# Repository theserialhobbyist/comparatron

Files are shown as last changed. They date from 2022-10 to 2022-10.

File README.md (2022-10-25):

# comparatron
Comparatron - a DIY digital optical comparator

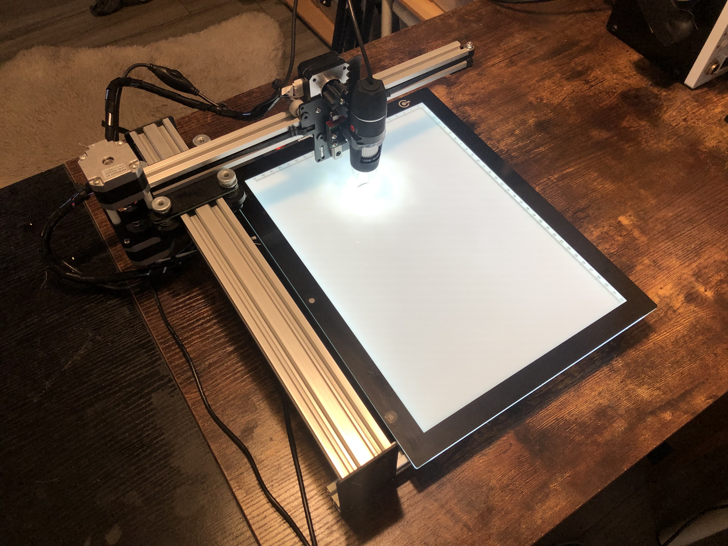
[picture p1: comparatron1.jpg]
Comparatron


This is a DIY digital optical comparator, which is an instrument used to take precise measurements of physical objects through visual means. Optical comparators cost tens of thousands of dollars, but Comparatron costs less than $500 to build (most of that cost is the CNC pen plotter).

It is essentially a USB digital microscope mounted to a CNC pen plotter. The microscope provides a very clear view of the object, while the CNC pen plotter lets us move the microscope with high precision. Additionally, an LED-backlit tracing board removes shadows so that we see clean edges.

The software interface lets users connect to and control the movement of the CNC pen plotter and create points, then export those points as a DXF that they can import into CAD software. This makes Comparatron very useful for reverse-engineering, as you can find the exact dimensions of a part (down to around +/-0.02mm). That's especially true for organic and irregular geometry that is difficult to measure with calipers, and for objects that are very small.

Demonstration Video:
ComparatronDemo (https://www.youtube.com/watch?v=9CRdngo2uUE)

-----------------------------------------------------------

Phyiscal build instructions are available at: https://www.instructables.com/Comparatron-an-Affordable-Digital-Optical-Comparat/

Parts needed for the build:

1. iDraw Pen Plotter 2.0 - A4 Size
2. Jiusion 40 to 1000x Magnification Endoscope
3. LitEnergy Portable A4 Tracing LED Copy Board Light Box
4. 3D-printed spur gear
5. 3D-printed microscope mount

Optional parts:

6. USB Hub
7. USB extension cable
8. 3M Commands strips (to attach light board and USB hub)
9. Zip ties (to tidy wiring)

-----------------------------------------------------------

Software notes:

The software is written in Python and uses the following modules: 
DearPyGUI
OpenCV
NumPy
PySerial
Serial Tools
EZDXF (full package)

I've only tested the software on Windows 10. It should work in other versions of Windows, but probably not on macOS or Linux (due to the way they handle COM ports). However, all of the modules are OS-agnostic, so it should be possible to tweak the Python code to work with other operating systems.

Both the Python script and a standalone Windows executable are available. The executable is ideal if you don't want to install the required dependencies yourself.

-----------------------------------------------------------

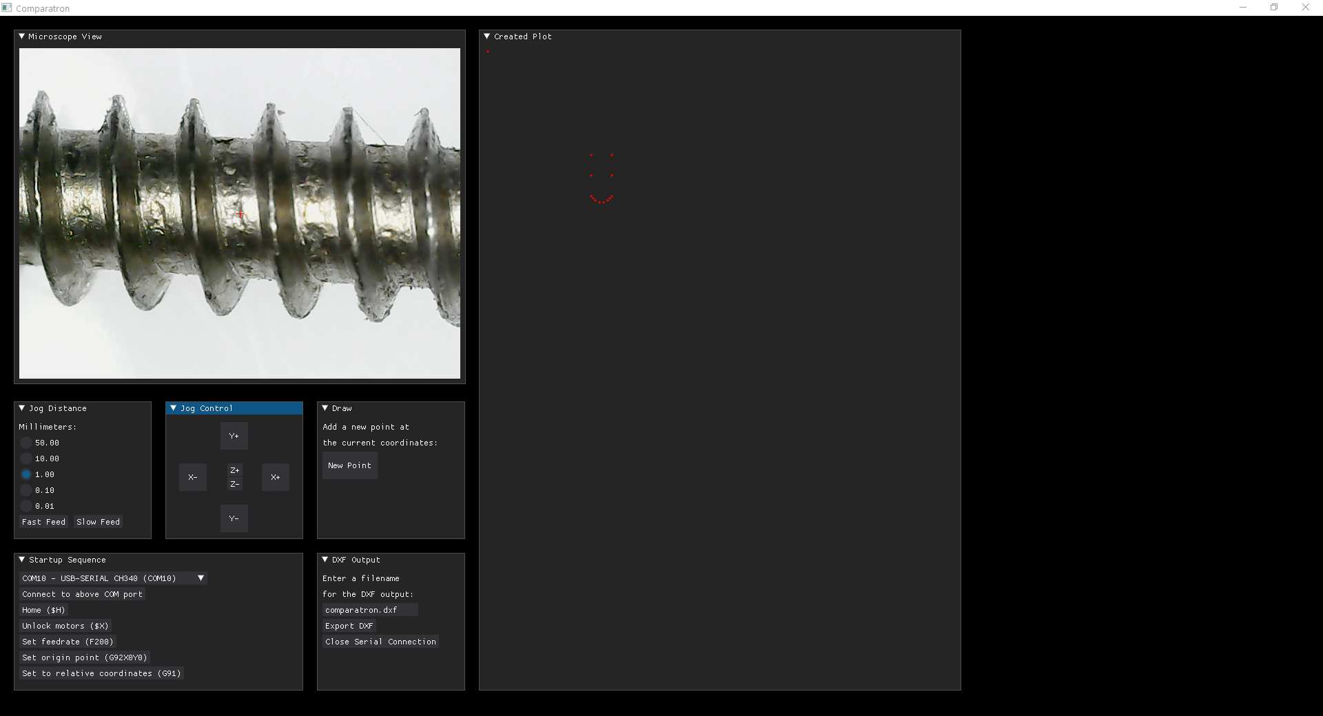
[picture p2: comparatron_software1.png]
Software View


Software usage:

I hope the software is intuitive, but just in case I'll cover the basics here.

Upon launching the software, you'll get a window filled with several other windows.

The top-left window is the view from the microscope. The script uses the first available camera. If this doesn't work properly, make sure no other webcams are connected to your computer. The crosshair reticle in the middle of the video feed is a reference for placing your points.

The right window shows a visualization of the plotted points. It represents the ENTIRE tracing board, so if the measured object is small then it won't take up much space in that window. This is not interactive and you can't edit or move the points, it is just a visual representation of the log of drawn points.

The top-left window below the video feed provides movement settings, including distance and speed. I recommend using "Slow Feed" for your actual measurements and only using "Fast Feed" for getting close to the object when you first start. 

The next window to the right is the jog control. This lets you move the microscope. Z adjustments should really only be used to focus the object. The machine homes to the top-right of the tracing board, so all Y-axis measurements are negative and you need to push the "Y-" button to move down onto the tracing board.

The next window to the right is for drawing tools. At this time, the only tool available is "New Point." That creates a point at the global WPS coordinates, both in the DXF file and in the visual representation in the "Created Plot" window. Other tools, such as lines, may be added in the future. But points are the most important, as you will do your actual drawing in CAD using those points for reference.

The bottom-left window provides everything for connecting to and setting up the pen plotter on startup. I recommend activating each command in order (top to bottom). Start by selecting the COM port of the iDraw machine from the drop-down menu. It should say something like "USB-SERIAL CH340" and the COM port number. Then click "Connect to the above COM port" to connect to the machine through serial (the Python console provides printed responses). Next, Home the machine, Unlock the motors, Set the feedrate, Set the origin point, and finally Set the machine to relative coordinates.

The last window is the "DXF Output" tool. Simply specify the filename you'd like, then click "Export DXF." It will save a DXF file with your chosen name in the same folder as the Python script/executable. You can do this as many times as you like. If you use the same filename, it will overwrite the original file. Or you can use a new filename. In both cases, it will contain all of the drawn points since you first launched the software. When you're finished, I recommend pressing "Close Serial Connection" so that you can reconnect to the machine later without power cycling it.

-----------------------------------------------------------

Suggested workflow:

1. Plug in USB cables for tracing board, microscope, and pen plotter.
2. Plug in DC power adapter for pen plotter.
3. Turn on the tracing board and the pen plotter.
4. Launch Comparatron software.
5. Connect to COM port and follow startup sequence.
6. Move Z axis up to gain clearance.
7. Use Fast Feed to move close to your object.
8. Switch to Slow Feed to find an edge.
9. Adjust Z axis until the edge is in focus.
10. Follow the edges at Slow Feed and add points to trace your object
11. Export DXF
12. Open Autodesk Fusion 360 or other CAD software (or even PCB design software)
13. Import the DXF (as millimeters)
14. Use the points as needed for your design

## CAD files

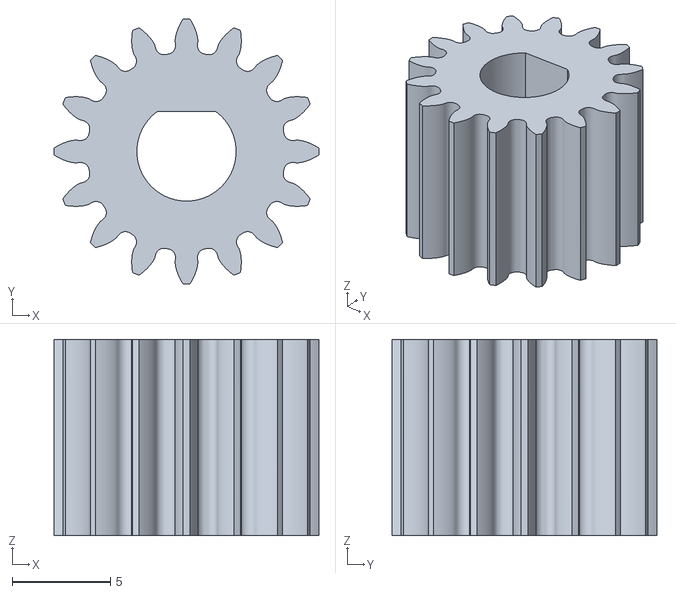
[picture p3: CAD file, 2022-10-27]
SpurGearV1.stl
13.5 x 13.5 x 10.0

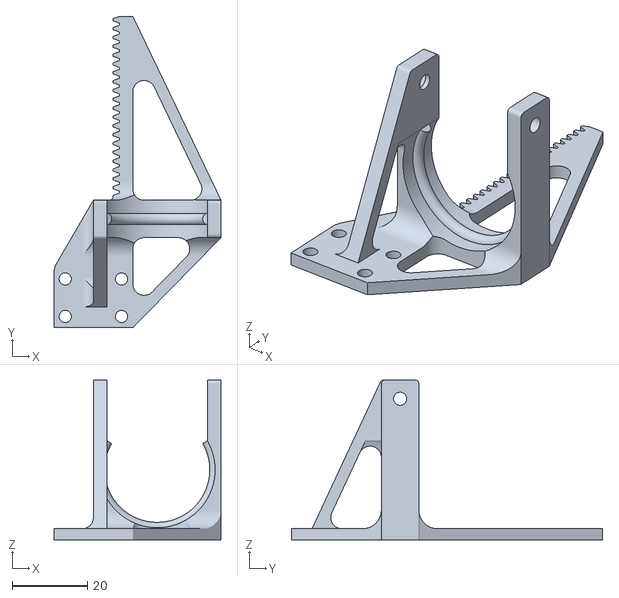
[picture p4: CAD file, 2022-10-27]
MicroscopeMountV1.stl
44.5 x 83.0 x 42.6

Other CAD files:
MicroscopeMountV1.obj
SpurGearV1.obj

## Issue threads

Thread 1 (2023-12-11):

ModuleNotFoundError: No module named 'dearpygui'

MesaCrash, 2023-12-11:
Can you tell me how to correct this error

MesaCrash, 2023-12-11:
ModuleNotFoundError: No module named 'dearpygui'

theserialhobbyist, 2023-12-11:
Have you installed DearPyGui? Instructions are here: https://github.com/hoffstadt/DearPyGui

MesaCrash, 2023-12-11:
I'm still getting an error and when I attempted to install dearpygui, it
tells me it can't find the file.

On Mon, Dec 11, 2023 at 1:54 PM Cameron Coward ***@***.***>
wrote:

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

MesaCrash, 2023-12-11:
Where should I put the files

On Mon, Dec 11, 2023 at 1:54 PM Cameron Coward ***@***.***>
wrote:

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

MesaCrash, 2023-12-11:
They are currently in the Downloads of the Pi folder.

On Mon, Dec 11, 2023 at 1:54 PM Cameron Coward ***@***.***>
wrote:

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

MesaCrash, 2023-12-11:
Where can I find this executable file that you speak of? " The executable
is ideal if you don't want to install the required dependencies yourself."

On Mon, Dec 11, 2023 at 1:54 PM Cameron Coward ***@***.***>
wrote:

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

theserialhobbyist, 2023-12-12:
GitHub won't let me upload large enough files for the executable. I'm not sure if this will work, but you can see if you can download it from my Google Drive: https://drive.google.com/file/d/1k0p8byzbNCzIcP1MF8HuCCXpsJs_N2kV/view?usp=sharing

MesaCrash, 2023-12-13:
It compiles now, but when I click RUN, it does nothing.

On Mon, Dec 11, 2023 at 7:29 PM Cameron Coward ***@***.***>
wrote:

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

theserialhobbyist, 2023-12-13:
You ran the executable on a Windows PC and nothing happened?

MesaCrash, 2023-12-13:
I tried the executable on windows and it would not run. I'm over that, and
went back to the Pi. I can successfully compile dearpygui and
successfully compile main.exe. I couldn't get main.exe to compile before
but now I can. But, they don't run, and I don't get any kind of message
that might help me troubleshoot.

On Wed, Dec 13, 2023 at 5:11 PM Cameron Coward ***@***.***>
wrote:

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

theserialhobbyist, 2023-12-13:
That's strange. Have you tried running it from an IDE on a Windows machine?

MesaCrash, 2023-12-13:
I have not. I am well versed in mechanics and electronics but not so much
in programming. I get it, to some degree but I get stuck sometimes, like
now. I have built this beautiful machine but need help with the Pi.

On Wed, Dec 13, 2023 at 5:22 PM Cameron Coward ***@***.***>
wrote:

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

MesaCrash, 2023-12-13:
You had mentioned other add-ons I might need, right?

On Wed, Dec 13, 2023 at 5:22 PM Cameron Coward ***@***.***>
wrote:

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

theserialhobbyist, 2023-12-13:
Unfortunately, programming isn't really my forte either. I kind of just cobbled the software together to make it work.

But I'm not sure it will run on a Pi. Some of the functions (like selecting a COM port) are specific to Windows. I think they could be rewritten to run on a Pi, but I'm not sure exactly how.

Do you have to run the software on a Pi, or do you have the option to run it on Windows?

Not sure what add-ons you'd need. It's been a while since I completed this project and my memory is fuzzy, but I don't think you need anything else. Just something that can open the DXFs after they're created.

MesaCrash, 2023-12-14:
I was under the impression it was supposed to run on a Pi. OK, let me go in
that direction and I will get back to you in a day or so. Are there any
other add-ons I will need?

On Wed, Dec 13, 2023 at 5:52 PM Cameron Coward ***@***.***>
wrote:

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

MesaCrash, 2023-12-14:
Btw, what are you using for a controller?

On Wed, Dec 13, 2023, 5:52 PM Cameron Coward ***@***.***>
wrote:

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

theserialhobbyist, 2023-12-14:
You shouldn’t need anything. The controller is just the one that came with
the plotter.

Thanks,
Cameron Coward

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

MesaCrash, 2023-12-14:
I did not buy the plotter. I had parts laying around, so I built one. I
thought Python scripts run on Pi only so I used a Pi. I now have Python on
my PC. I tried to install the scripts and still get the same error. I'm
concerned there is a certain path that all folders should be installed in.
I'm working on that now.

On Wed, Dec 13, 2023 at 6:35 PM Cameron Coward ***@***.***>
wrote:

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

theserialhobbyist, 2023-12-14:
Ah, I see.

No, Python itself is platform agnostic—though certain modules might only
work on specific platforms.

The plotter uses a GRBL controller (I think), so others of that type should
work in theory. But I'm not positive about that.

As far as installing Python, you should be able to just install Python 3
from their website, then use the pip installer for the required modules.

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

--
Thanks,
Cameron Coward

MesaCrash, 2023-12-14:
The error I get in Python is: The desired package for installation could
not be found

On Wed, Dec 13, 2023 at 6:35 PM Cameron Coward ***@***.***>
wrote:

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

theserialhobbyist, 2023-12-14:
You get that when you run:

"pip install dearpygui"

Is that correct?

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

--
Thanks,
Cameron Coward

MesaCrash, 2023-12-14:
Python runs but I am trying to get "main" to run. That is when I get the
error message.  When I type "pip install dearpygui" I get an syntax error
message. It doesn't like the word install.

I have a spare grbl controller. I will use it.

On Thu, Dec 14, 2023 at 11:37 AM Cameron Coward ***@***.***>
wrote:

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

theserialhobbyist, 2023-12-14:
Maybe try "pip3 install dearpygui" instead?

If that doesn't work, I'm not really sure what the issue is. My Python
knowledge is pretty limited.

It might have something to do with PATH. I'm no expert on that, but it
might give you some direction when googling.

On Thu, Dec 14, 2023 at
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

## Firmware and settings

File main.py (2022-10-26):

# Comparatron V1.0
# by Cameron Coward
# http://www.cameroncoward.com

# DearPyGUI for GUI, OpenCV for video capture, NumPy for calculations,
#PySerial for communication with machine, EXDXF for creating DXF drawings, sys for clean exit
import dearpygui.dearpygui as dpg
import cv2 as cv
import numpy as np
import serial
import serial.tools.list_ports
import ezdxf
import sys

doc = ezdxf.new(dxfversion="R2010") #create new DXF drawing
doc.layers.add("COMPARATRON_OUTPUT", color=2) #add layer for our drawing
msp = doc.modelspace() #create a modelspace for our drawing

ser = None #for use with the serial connection later
ports = serial.tools.list_ports.comports()

dpg.create_context() #create DearPyGUI object
dpg.create_viewport(title='Comparatron by Cameron Coward', width=1280, height=720) #main program window
dpg.setup_dearpygui() #setup DearPyGUI

vid = cv.VideoCapture(0) #create OpenCV object with first video feed available
ret, frame = vid.read() #pull frame from video feed

# get the video parameters
frame_width = vid.get(cv.CAP_PROP_FRAME_WIDTH)
frame_height = vid.get(cv.CAP_PROP_FRAME_HEIGHT)
video_fps = vid.get(cv.CAP_PROP_FPS)

# calculate center point for adding crosshair reticle
target_x = int(frame_width / 2)
target_y = int(frame_height / 2)

data = np.flip(frame, 2)  # flip video BGR colorspace to RGB
data = data.ravel()  # flatten camera data to 1D
data = np.asfarray(data, dtype='f')  # change data type to 32bit floats
texture_data = np.true_divide(data, 255.0)  # normalize image data to prepare for GPU

def connect_to_com(): #connect to the COM port specified by user
    global ser #to use the same object we already created
    com_port_full = str((dpg.get_value("port_selection"))) #pull COM port selection as a string
    com_port = com_port_full.split(' ') #split at " " so first string is just the COM port
    print("Trying to connect to:", com_port[0])
    ser = serial.Serial(com_port[0], 115200, bytesize=8, parity='N', stopbits=1, timeout=None, xonxoff=1, rtscts=0) #connect to COM port
    ser_in = ser.readline() #listen for connection status from machine
    print(ser_in)
    ser_in = ser.readline() #listen for connection status from machine
    print(ser_in)

def home_machine(): #use the built-in GRBL command to home machine
    global ser #to use the same object we already created
    ser.write(b'$H\r') #home command and return as bytes
    ser_in = ser.readline()
    print(ser_in)
    
def unlock_machine(): #use the built-in GRBL command to unlock machine motors
    global ser #to use the same object we already created
    ser.write(b'$X\r')
    ser_in = ser.readline()
    print(ser_in)
    
def set_feed(): #set feedrate to 200
    global ser #to use the same object we already created
    ser.write(b'F200\r')
    ser_in = ser.readline()
    print(ser_in)
    
def set_origin(): #set the WPS coordinate origins to zero
    global ser #to use the same object we already created
    ser.write(b'G92X0Y0\r')
    ser_in = ser.readline()
    print(ser_in)
    
def set_rel(): #set G91 (to use relative coordinates from now on)
    global ser #to use the same object we already created
    ser.write(b'G91\r')
    ser_in = ser.readline()
    print(ser_in)
    
def jog_x_pos(): #move X axis right by the set amount
    global ser #to use the same object we already created
    distance = (dpg.get_value("JD"))
    command_string = ("G1X" + distance + "Y0\r")
    command_bytes = command_string.encode()
    ser.write(command_bytes)
    ser_in = ser.readline()
    print(ser_in)
    
def jog_x_neg(): #move X axis left by the set amount
    global ser #to use the same object we already created
    distance = (dpg.get_value("JD"))
    command_string = ("G1X-" + distance + "Y0\r")
    command_bytes = command_string.encode()
    ser.write(command_bytes)
    ser_in = ser.readline()
    print(ser_in)
    
def jog_y_pos(): #move Y axis up by the set amount
    global ser #to use the same object we already created
    distance = (dpg.get_value("JD"))
    command_string = ("G1X0Y" + distance + "\r")
    command_bytes = command_string.encode()
    ser.write(command_bytes)
    ser_in = ser.readline()
    print(ser_in)
    
def jog_y_neg(): #move Y axis down by the set amount
    global ser #to use the same object we already created
    distance = (dpg.get_value("JD"))
    command_string = ("G1X0Y-" + distance + "\r")
    command_bytes = command_string.encode()
    ser.write(command_bytes)
    ser_in = ser.readline()
    print(ser_in)
    
def jog_z_pos(): #move Z axis up by the set amount
    global ser #to use the same object we already created
    distance = (dpg.get_value("JD"))
    if float(distance) > 10.00: #prevent moving Z axis by 50.00
        distance = "10.00"
    command_string = ("G1Z" + distance + "\r")
    command_bytes = command_string.encode()
    ser.write(command_bytes)
    ser_in = ser.readline()
    print(ser_in)
    
def jog_z_neg(): #move Z axis down by the set amount
    global ser #to use the same object we already created
    distance = (dpg.get_value("JD"))
    if float(distance) > 10.00: #prevent moving Z axis by 50.00
        distance = "10.00"
    command_string = ("G1Z-" + distance + "\r")
    command_bytes = command_string.encode()
    ser.write(command_bytes)
    ser_in = ser.readline()
    print(ser_in)
    
def fast_feed(): #set feedrate to 1000 for quick movement
    global ser #to use the same object we already created
    ser.write(b'F1000\r')
    ser_in = ser.readline()
    print(ser_in)
    
def create_new_point():
    global ser #to use the same object we already created
    ser.write(b'?\r') #queries the current coordinates
    ser_in = ser.readline()
    ser_str = ser_in.decode("utf-8") #convert the returned coordinates from bytes to string
    print(ser_str)
    ser_str = ser_str.removeprefix('<Idle|WPos:') #remove everything before the first (X) coordinate
    print(ser_str)
    coords = ser_str.split(',') #split the rest of the string by commas
    print(coords[0]) #first split is X coordinates
    print(coords[1]) #second split is Y coordinates
    point_x = float(coords[0]) #convert X coordinate string to float
    point_y = float(coords[1]) #convert Y coordinate string to float
    global msp #to use the same modelspace we already created
    msp.add_point((point_x,point_y), dxfattribs={"color": 7}) #create a point in the DXF at the coordinates
    draw_x = 5 + int(3 * point_x) #scale coordinate for use in the DearPyGUI drawing plot
    draw_y = 5 + int(-3 * point_y) #scale coordinate for use in the DearPyGUI drawing plot
    dpg.draw_circle(center=(draw_x, draw_y), radius=1, color=(255, 0, 0, 255), thickness=1, parent="plot") #add a circle to the DearPyGUI drawing plot at coordinates
    ser_in = ser.readline()
    print(ser_in)
    
def export_dxf_now(): #save the ongoing DXF file as the filename set by the user
    dxf_filename = (dpg.get_value("dxf_name"))
    doc.saveas(dxf_filename)
    print("DXF output to: ",dxf_filename)
    
def close_ser_now(): #close the serial connection to the machine, allowing for a new connection without a power cycle
    vid.release() #closes video feed
    print("Released video")
    global ser #to use the same object we already created
    
    if ser.isOpen() == True:
        ser.close() #closes the serial COM port connection to machine
        print("Closed serial connection")
    else:
        print("No open serial connection to close")
    
    dpg.destroy_context()
    print("Destroyed DearPyGUI context")
    sys.exit()

with dpg.texture_registry(show=False): #creates a "texture" of the video feed so we can display it
    dpg.add_raw_texture(frame.shape[1], frame.shape[0], texture_data, tag="texture_tag", format=dpg.mvFormat_Float_rgb)

with dpg.window(label="Microscope View", pos=(20,20), no_close=True): #window showing the video feed
    dpg.add_image("texture_tag")
    
with dpg.window(label="Jog Distance", pos=(20,frame_height+80), width=200, height=200, no_close=True): #window with the jog distance settings
    dpg.add_text("Millimeters:")
    def print_me(sender, data): #for some reason this is necessary for the radio buttons to work right
        print(dpg.get_value("JD")) #for some reason this is necessary for the radio buttons to work right
    dpg.add_radio_button(tag="JD", items=['50.00', '10.00', '1.00', '0.10', '0.01'], default_value='10.00', callback=print_me)
    with dpg.group(horizontal=True):
        dpg.add_button(tag="fast_feed", label="Fast Feed", callback=fast_feed)
        dpg.add_button(tag="slow_feed", label="Slow Feed", callback=set_feed)

with dpg.window(label="Jog Control", pos=(240,frame_height+80), width=200, height=200, no_close=True): #window with the jog controls
    dpg.add_button(tag="x_pos", label="X+", pos=(140,90), width=40, height=40, callback=jog_x_pos)
    dpg.add_button(tag="x_neg", label="X-", pos=(20,90), width=40, height=40, callback=jog_x_neg)
    dpg.add_button(tag="y_pos", label="Y+", pos=(80,30), width=40, height=40, callback=jog_y_pos)
    dpg.add_button(tag="y_neg", label="Y-", pos=(80,150), width=40, height=40, callback=jog_y_neg)
    dpg.add_button(tag="z_pos", label="Z+", pos=(90,90), callback=jog_z_pos)
    dpg.add_button(tag="z_neg", label="Z-", pos=(90,110), callback=jog_z_neg)
    
with dpg.window(label="Startup Sequence", pos=(20,frame_height+300), width=420, height=200, no_close=True): #window with the startup sequence buttons
    dpg.add_combo(tag="port_selection", items=ports)
    dpg.add_button(tag="connect_com", label="Connect to above COM port", callback=connect_to_com)
    dpg.add_button(tag="mach_home", label="Home ($H)", callback=home_machine)
    dpg.add_button(tag="mach_unlock", label="Unlock motors ($X)", callback=unlock_machine)
    dpg.add_button(tag="mach_feed", label="Set feedrate (F200)", callback=set_feed)
    dpg.add_button(tag="mach_origin", label="Set origin point (G92X0Y0)", callback=set_origin)
    dpg.add_button(tag="mach_rel", label="Set to relative coordinates (G91)", callback=set_rel)
    
with dpg.window(label="Draw", pos=(460,frame_height+80), width=215, height=200, no_close=True): #window with drawing controls (just adding a point for now)
    dpg.add_text("Add a new point at")
    dpg.add_text("the current coordinates:")
    dpg.add_button(tag="new_point", label="New Point", width=80, height=40, callback=create_new_point)
    
with dpg.window(label="DXF Output", pos=(460,frame_height+300), width=215, height=200, no_close=True): #window with DXF export controls
    dpg.add_text("Enter a filename")
    dpg.add_text("for the DXF output:")
    dpg.add_input_text(tag="dxf_name", default_value="comparatron.dxf")
    dpg.add_button(tag="export_dxf", label="Export DXF", callback=export_dxf_now)
    dpg.add_separator()
    dpg.add_text("Close serial and")
    dpg.add_text("release video:")
    dpg.add_button(tag="close_ser", label="Clean exit", callback=close_ser_now)
    
with dpg.window(label="Created Plot", pos=(frame_width+55, 20), width=700, height=960, no_close=True): #window that shows a visualization of plotted points
    with dpg.drawlist(tag="plot", width=660, height=920): #the drawing space for the plot
        dpg.draw_circle(center=(100, 200), radius=2, color=(255, 0, 0, 255), thickness=2, show=False) #hidden circle, necessary because drawlist requires a child object to initialize
    

dpg.show_viewport() #renders the DearPyGUI viewport
dpg.maximize_viewport() #maximizes the window
while dpg.is_dearpygui_running(): #DearPyGUI render loop

    if vid.isOpened():
        ret, frame = vid.read()
        cv.drawMarker(frame, (target_x, target_y), (0, 0, 255), cv.MARKER_CROSS, 10, 1)
        data = np.flip(frame, 2)
        data = data.ravel()
        data = np.asfarray(data, dtype='f')
        texture_data = np.true_divide(data, 255.0)
        dpg.set_value("texture_tag", texture_data)
        # DearPyGUI framerate is tied to video feed framerate in this loop
    
    dpg.render_dearpygui_frame()

vid.release() #closes video feed
dpg.destroy_context() #closes DearPyGUI objects

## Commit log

2022-10-25 Initial upload
    Initial upload of the Python script and 3D-printable files
    [MicroscopeMount.obj, SpurGear.obj]
2022-10-27 New 3D-printed part designs
    Dramatically improved strength and rigidity of microscope mount, reducing flex and increasing accuracy.
    Also changed rack and pinion parameters to keep the weight of the microscope from pulling the Z axis down when power is off.
    [MicroscopeMountV1.obj, MicroscopeMountV1.stl, SpurGearV1.obj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]
